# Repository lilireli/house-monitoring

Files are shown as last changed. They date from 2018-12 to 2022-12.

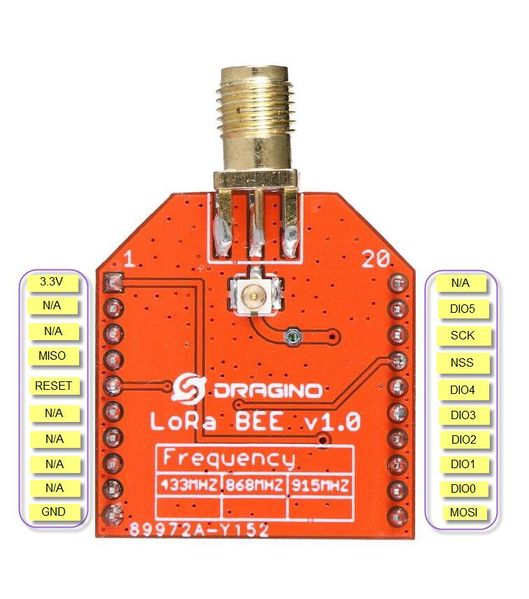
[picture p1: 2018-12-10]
sensor-transmitter/building-material/Dragino_LoRa_Bee.jpg

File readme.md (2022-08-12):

# House-Monitoring

This project contains the code and the schematics (3D printer code and electronic diagrams) for a deported temperature sensor.
It contains three parts:

- An Arduino sensor which contains a temperature sensor and a Lora transmitter,
- A Raspberry which contains a Lora receiver to get the data from the Arduino, and which sends it to a webserver,
- A Webserver which remembers past temperatures and displays it.

An example of usecase can be found in a family house where a wintergarden is at the back of the house, quite far away. 
However, it is necessary to monitor the temperature of this glass house. 
Thus, the Arduino is placed in the glass house, and the raspberry in the house, to control from afar the temperature. 
When not at home, the temperature can still be monitored with the web application.

## Sensor Transmitter
This is the Arduino part.

It contains:
- an arduino Nano
- a temperature sensor
- a Lora transmitter
- a LED (to check the device is working)

The code is done in C++, and compiled with Platformio.

## Receiver Transmitter
This is the Raspberry part.

It contains:
- a Raspberry
- a Lora receiver
- a buzzer (to alarm people when the temperature gets dangerous for the plants!)
- a LED screen (to print the current temperature and lowest temperature in the past 24 hours)

The code is done in C++.

Installation is done with cmake (version depends on the server your using)

```bash
mkdir build
cd build
sudo apt-get install libboost-all-dev
cmake ..
make
./house_transmitter --url http://localhost:5000/temp/add --auth-key 12345
```

## Server Monitoring
This is the webserver.

Initially it was done in C++, Vue.js (server-monitoring), in its new version it is in Python Django, React (server-monitoring2).

Installation with Python is done with virtualenv.

```bash
cd server-monitoring2
virtualenv venv
source venv/bin/activate
pip install requirements.txt
```

The application is currently running on Heroku
- To run locally https://devcenter.heroku.com/articles/getting-started-with-python#run-the-app-locally
- To deploy https://devcenter.heroku.com/articles/getting-started-with-python#deploy-the-app

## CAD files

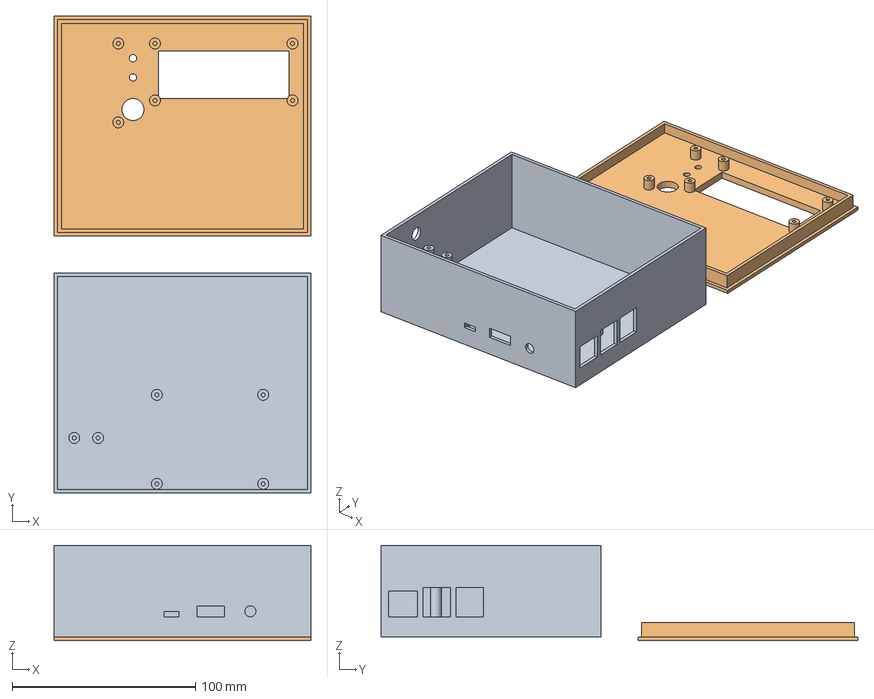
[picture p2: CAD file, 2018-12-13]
receiver-transmitter2/building-material/3d-printer/receptor.fcstd
140.0 x 260.0 x 52.0 mm
pocket lora antenna

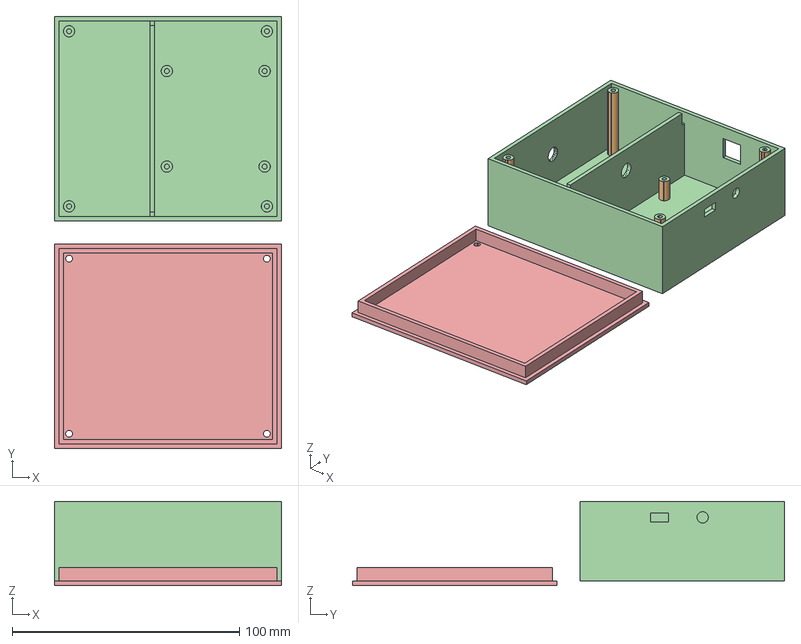
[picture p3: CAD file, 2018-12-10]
sensor-transmitter/building-material/3d-printer/sensor.fcstd
100.0 x 190.0 x 37.0 mm
footTop2
footTop2 (Meshed)
Pocket010 (Meshed)

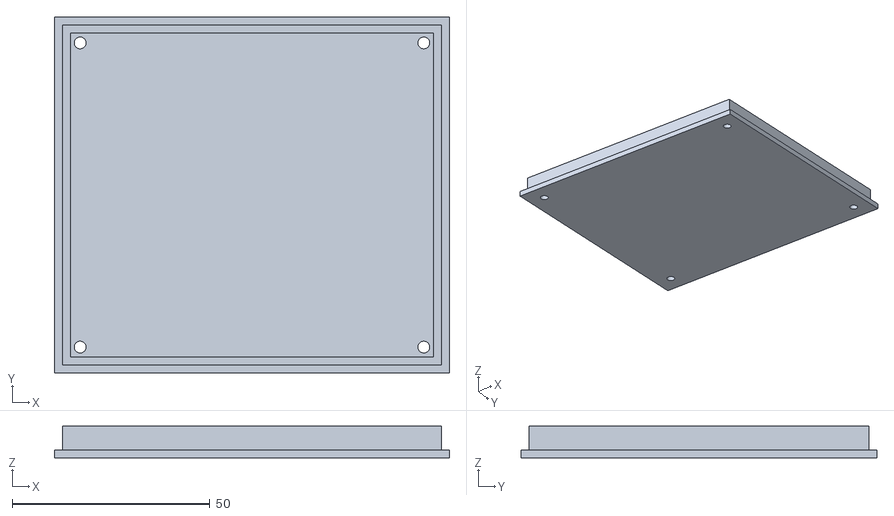
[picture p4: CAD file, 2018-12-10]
sensor-transmitter/building-material/3d-printer/arduino_top.stl
100.0 x 90.0 x 8.00

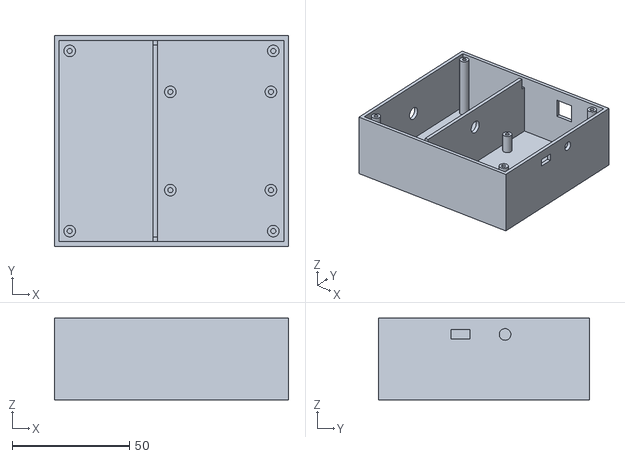
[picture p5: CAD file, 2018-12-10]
sensor-transmitter/building-material/3d-printer/arduino_bottom.stl
100.0 x 90.0 x 35.0

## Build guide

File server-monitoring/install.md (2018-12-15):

# Installation needs

## ZMQ
sudo apt-get install libzmq3-dev

## Sqlite
sudo apt-get install libsqlite3 libsqlite3-dev

## Boost
libboost-all-dev

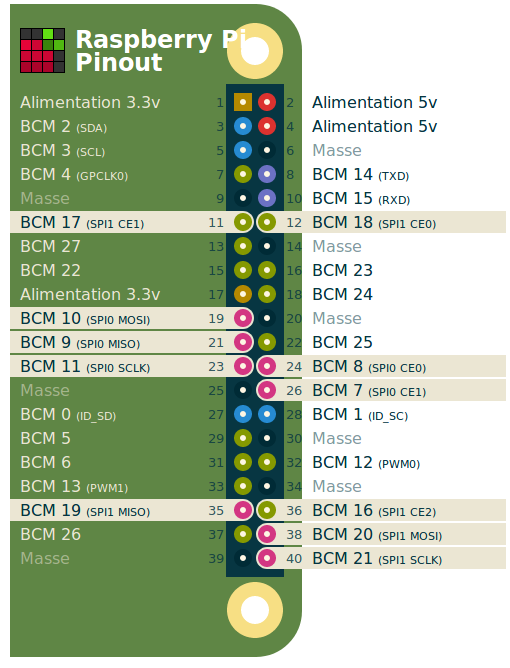
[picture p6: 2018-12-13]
receiver-transmitter2/building-material/Raspberry_pins.png

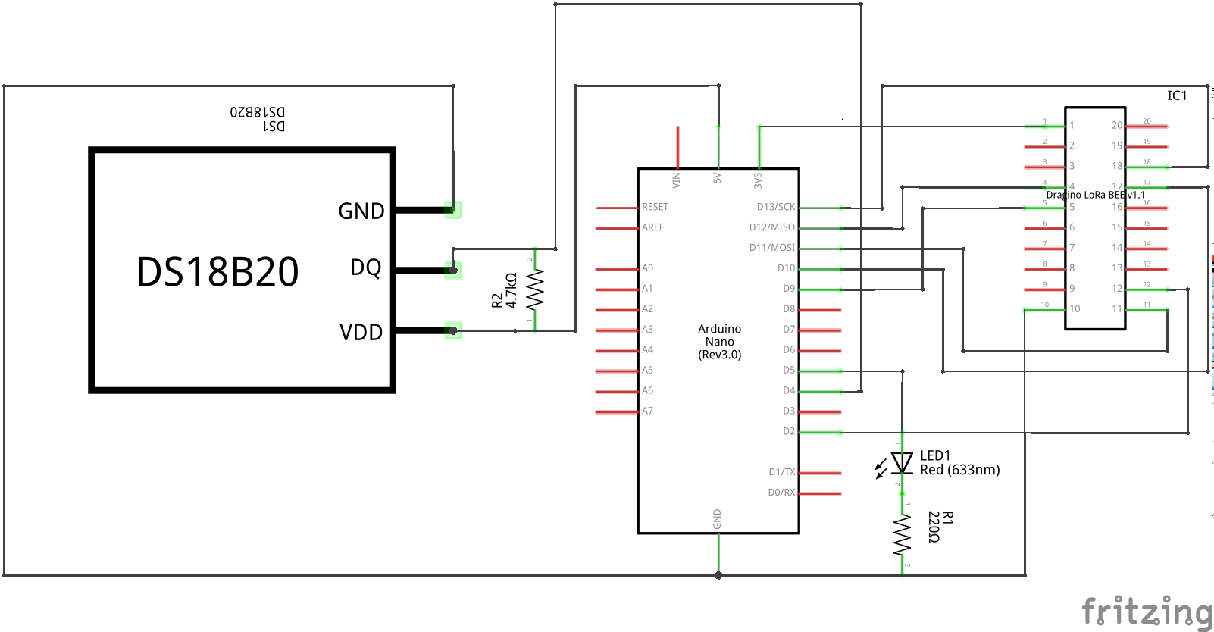
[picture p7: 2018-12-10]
sensor-transmitter/building-material/schema_arduino.png

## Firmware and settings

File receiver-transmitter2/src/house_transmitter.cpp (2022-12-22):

// Raspberry transmitter to retrieve the temperature through LoRa and resend it through Zmq

// Dragino Lora SPI Pins
///                 Raspberry    RFM95/96/97/98
///                 GND----------GND   (ground in)
///                 3V3----------3.3V  (3.3V in)
///  interrupt 0 pin 24----------DIO0  (interrupt request out)
///           SS pin 26----------NSS   (chip select in)
///          SCK pin 23----------SCK   (SPI clock in)
///         MOSI pin 19----------MOSI  (SPI Data in)
///         MISO pin 21----------MISO  (SPI Data out)

#include <house_transmitter.h>

namespace pt = boost::property_tree;
namespace po = boost::program_options;

//// Info Screen ////
InfoScreen::InfoScreen() : m_lcd(LCD_RS, LCD_E, LCD_D4, LCD_D5, LCD_D6, LCD_D7)
{
    m_lcd.begin(16, 2);
}

void InfoScreen::print_line_one(std::string text)
{
    m_lcd.setCursor(0, 0);
    m_lcd.print("                 ");
    m_lcd.setCursor(0, 0);
    m_lcd.print(text.c_str());
}

void InfoScreen::print_line_two(std::string text)
{
    m_lcd.setCursor(0, 1);
    m_lcd.print("                 ");
    m_lcd.setCursor(0, 1);
    m_lcd.print(text.c_str());
}

//// IHM ////
IHM::IHM() : m_alarm_enabled(false), m_running(true), m_alarm_running(false), m_noise_running(false), m_last_received(time(0))
{
    // Initialize actuators
    pinMode(LED_GREEN, OUTPUT);
    pinMode(LED_RED, OUTPUT);
    pinMode(ALARM, OUTPUT);

    digitalWrite(LED_GREEN, LOW);
    digitalWrite(LED_RED, LOW);
    digitalWrite(ALARM, LOW);

    m_info_screen.print_line_one("Hello");
    m_info_screen.print_line_two("v3");

    m_led_thread = std::make_unique<std::thread>(std::thread([this] {
        blink_led();
    }));
}

IHM::~IHM()
{
    std::cout << "Shutting down alarms" << std::endl;
    stop_alarm(99);
    m_running = false;
    m_led_thread->join();
    digitalWrite(LED_GREEN, LOW);
    digitalWrite(LED_RED, LOW);
    digitalWrite(ALARM, LOW);

    m_info_screen.print_line_one("Program not");
    m_info_screen.print_line_two("running");
}

void IHM::start_alarm(std::string error_msg)
{
    m_alarm_running = true;

    if (!m_noise_running && m_alarm_enabled && error_msg != "No webserver" && difftime(time(0), m_last_received) > WAITING_TIME_ALARM) {
        m_alarm_thread = std::make_unique<std::thread>(std::thread([this] {
            make_noise();
        }));
    }

    m_info_screen.print_line_two(error_msg);
}

void IHM::stop_alarm(float min_temp)
{
    m_alarm_running = false;
    m_last_received = time(0);

    if (m_noise_running) {
        m_alarm_thread->join();
    }

    std::stringstream temp_stream;
    temp_stream << std::fixed << std::setprecision(1) << min_temp;
    m_info_screen.print_line_two("min 24h:  " + temp_stream.str() + " C");
}

int IHM::print_temp(float temp)
{
    std::stringstream temp_stream;
    temp_stream << std::fixed << std::setprecision(1) << temp;
    m_info_screen.print_line_one("temp:     " + temp_stream.str() + " C");
}

void IHM::no_temp()
{
    m_info_screen.print_line_one("no temp");
}

void IHM::set_alarm_enabled(bool enable)
{
    std::cout << "Alarm set to " << enable << std::endl;
    m_alarm_enabled = enable;

    if (m_noise_running && !m_alarm_enabled) {
        m_alarm_thread->join();
    }
}

void IHM::make_noise()
{
    m_noise_running = true;

    while (m_alarm_running && m_alarm_enabled) {
        digitalWrite(ALARM, HIGH);
        std::this_thread::sleep_for(std::chrono::milliseconds(500));
        digitalWrite(ALARM, LOW);
        std::this_thread::sleep_for(std::chrono::milliseconds(500));
    }

    m_noise_running = false;
}

void IHM::blink_led()
{
    int current_led = LED_RED;

    while (m_running) {
        if (m_alarm_running) {
            current_led = LED_RED;
        } else {
            current_led = LED_GREEN;
        }

        digitalWrite(current_led, HIGH);
        std::this_thread::sleep_for(std::chrono::milliseconds(1000));
        digitalWrite(current_led, LOW);
        std::this_thread::sleep_for(std::chrono::milliseconds(1000));
    }
}

// LoRa Receiver ////
LoraReceiver::LoraReceiver() : m_rf95(RF_CS_PIN)
{
    // Initialize Pins
    if (!bcm2835_init()) {
        throw std::string("bcm2835_init() Failed\n\n");
    }

    std::cout << "RF95 CS=GPIO%d" << RF_CS_PIN
              << ", RST=GPIO%d" << RF_RST_PIN
              << std::endl;

    // Pulse a reset on module
    pinMode(RF_RST_PIN, OUTPUT);
    digitalWrite(RF_RST_PIN, LOW);
    bcm2835_delay(150);
    digitalWrite(RF_RST_PIN, HIGH);
    bcm2835_delay(100);

    if (!m_rf95.init()) {
        throw std::string("\nRF95 module init failed, Please verify wiring/module\n");
    }

    // check your country max power useable, in EU it's +14dB
    m_rf95.setTxPower(14, false);

    // Adjust Frequency
    m_rf95.setFrequency(RF_FREQUENCY);

    // If we need to send something
    m_rf95.setThisAddress(RF_NODE_ID);
    m_rf95.setHeaderFrom(RF_NODE_ID);

    // Be sure to grab all node packet
    // we're sniffing to display, it's a demo
    m_rf95.setPromiscuous(true);

    // We're ready to listen for incoming message
    m_rf95.setModeRx();

    std::cout << " OK NodeID=" << RF_NODE_ID << " @ "
              << std::fixed << std::setw(3) << std::setprecision(2)
              << RF_FREQUENCY << "MHz\n"
              << std::endl;
}

LoraReceiver::~LoraReceiver()
{
    std::cout << "Closing Lora connection" << std::endl;
    bcm2835_close();
}

int LoraReceiver::recv(float *temp)
{
    // We allow a timeout before sending error
    for (int i = 0; i < 60; i++) {
        if (m_rf95.available()) {
            // Should be a message for us now
            uint8_t buf[RH_RF95_MAX_MESSAGE_LEN];
            uint8_t len = sizeof(buf);

            if (m_rf95.recv(buf, &len)) {
                try {
                    std::cout << "Data: " << (char *)buf << std::endl;

                    // We need to remove unuseful characters at the end of the string
                    std::string req_corrupt = std::string((char *)buf);
                    std::size_t req_corrupt_end = req_corrupt.find("}");

                    if (req_corrupt_end == std::string::npos) {
                        std::cout << "Received badly formatted message";
                        throw std::string("Badly formatted\n");
                    }

                    std::istringstream req(req_corrupt.substr(0, req_corrupt_end + 1));
                    pt::ptree root;

                    pt::read_json(req, root);
                    // Not used yet -> std::string device = root.get<std::string>("id");
                    *temp = root.get<float>("temp");

                    return 1;
                } catch (...) {
                    std::cout << "No temperature received from sensor" << std::endl;
                }
            }
        }

        // wait one more sec to have result
        bcm2835_delay(1000);
    }

    // Alert no data received after one minute
    std::cout << "No temperature received from sensor" << std::endl;
    return -1;
}

//// HTTP Sender ////
int HttpSender::add_new_value(float temp, std::string status, bool *alarm_enabled)
{
    time_t now = time(0);
    int hasFailed = 0;

    if (m_curr_bucket == 0) {
        m_curr_bucket = now;
    }

    if (difftime(now, m_curr_bucket) > DB_INSERT_INTERVAL) {
        std::cout << "Sending data\n";
        float average = std::accumulate(m_temps.begin(), m_temps.end(), 0.0) / m_temps.size();

        hasFailed = send_temperature(m_curr_bucket, average, status, alarm_enabled);

        m_curr_bucket = now;
        m_temps.clear();
    }

    m_temps.push_back(temp);

    return hasFailed;
}

int HttpSender::send_temperature(time_t datetime, float temp, std::string status, bool *alarm_enabled)
{
    try {
        // check datetime
        struct tm *timeinfo = localtime(&datetime);
        char datetime_str[30];
        strftime(datetime_str, 30, "%Y-%m-%dT%H:%M:%S", timeinfo);

        // create message
        std::ostringstream body_stream;

        body_stream << std::setprecision(2) << std::fixed
                    << "datetime=" << datetime_str << "&"
                    << "temperature=" << temp << "&"
                    << "alarm_current=" << status << "&"
                    << "auth_key=" << m_auth_key;

        std::string body = body_stream.str();

        // send it
        http::Request request{m_url};

        const auto response = request.send("POST", body, {{"Content-Type", "application/x-www-form-urlencoded"}});

        std::string result = std::string{response.body.begin(), response.body.end()};

        std::cout << "Received from webserver: " << result << '\n';

        if (result == "{\"alarm\": \"on\"}") {
            std::cout << "Alarm enabled\n";
            *alarm_enabled = true;
        } else {
            std::cout << "Alarm disabled\n";
            *alarm_enabled = false;
        }

    } catch (const std::exception &e) {
        std::cerr << "Request failed, error: " << e.what() << '\n';
        return 1;
    }

    return 0;
}

TempKeeper::TempKeeper()
{
    for (int i = 0; i < SIZE_TEMP_KEEPER; i++) {
        m_temp_24h.push_back(99);
    }
}

void TempKeeper::add(float temp)
{
    time_t now = time(0);
    struct tm *timeinfo = localtime(&now);
    int approx_curr_pos = 60 * timeinfo->tm_hour + timeinfo->tm_min;
    int curr_pos = approx_curr_pos / PRECISION_KEEPER;

    // Erase old values
    int erase_pos = (curr_pos < SIZE_TEMP_KEEPER - 1) ? curr_pos + 1 : 0;
    m_temp_24h[erase_pos] = 99;

    // Compare new one with running 15 min
    if (m_temp_24h[curr_pos] > temp) {
        m_temp_24h[curr_pos] = temp;
    }
}

float TempKeeper::min_24h()
{
    auto min = std::min_element(m_temp_24h.begin(), m_temp_24h.end());
    return *min;
}

//Flag for Ctrl-C
volatile sig_atomic_t force_exit = false;

void sig_handler(int sig)
{
    std::cout << "\nBreak received, exiting!" << std::endl;
    force_exit = true;
}

// Main Function
int main(int argc, const char *argv[])
{
    // * Parsing arguments *
    std::string url, auth_key;

    po::options_description desc("Transmitter for house-monitoring project");
    desc.add_options()("help,h", "produce help message")("url", po::value<std::string>(), "defines to which url send the data")("auth-key", po::value<std::string>(), "defines the key to authenticate to the server");

    po::variables_map vm;
    po::store(po::parse_command_line(argc, argv, desc), vm);
    po::notify(vm);

    if (vm.count("help")) {
        std::cout << desc << std::endl;
        return 1;
    }

    // Deactivate server as long as no option found
    // if (vm.count("url")) {
    //     url = vm["url"].as<std::string>();
    // } else {
    //     std::cout << "No url was provided." << std::endl;
    //     return 1;
    // }

    // if (vm.count("auth-key")) {
    //     auth_key = vm["auth-key"].as<std::string>();
    // } else {
    //     std::cout << "No auth-key was provided." << std::endl;
    //     return 1;
    // }

    // * Main program *
    std::cout << "Starting program" << std::endl;

    // Register handler
    signal(SIGINT, sig_handler);

    LoraReceiver lora_receiver;
    // HttpSender http_sender(url, auth_key);
    IHM ihm;
    TempKeeper temp_keeper;

    std::map<std::string, std::string> errors = {
        {"tempLow", "Temp too low"},
        {"errArduino", "No temp received"},
        {"errWebserver", "No webserver"}};

    while (!force_exit) {
        float temp = 99;
        bool alarm_enabled = ihm.get_alarm_enabled();
        std::string status = "ok";
        std::string print_status = "";

        if (lora_receiver.recv(&temp) > 0) {
            temp_keeper.add(temp);
            ihm.print_temp(temp);
            if (temp < TRIGGER_TEMP) {
                status = "tempLow";
            }
        } else {
            ihm.no_temp();
            status = "errArduino";
        }

        // if (http_sender.add_new_value(temp, status, &alarm_enabled) > 0) {
        //     if (status == "ok") {
        //         status = "errWebserver";
        //     }
        // }

        // if (ihm.get_alarm_enabled() != alarm_enabled) {
        //     ihm.set_alarm_enabled(alarm_enabled);
        // }

        // if (status == "ok") {
        //     ihm.stop_alarm(temp_keeper.min_24h());
        // } else {
        //     ihm.start_alarm(errors[status]);
        // }
    }

    return 0;
}

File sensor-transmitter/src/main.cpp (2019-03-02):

// Arduino sensor to retrieve the temperature and send it through LoRa

// Dragino Lora SPI Pins
///                 Arduino      RFM95/96/97/98
///                 GND----------GND   (ground in)
///                 3V3----------3.3V  (3.3V in)
/// interrupt 0 pin D2-----------DIO0  (interrupt request out)
///          SS pin D10----------NSS   (chip select in)
///         SCK pin D13----------SCK   (SPI clock in)
///        MOSI pin D11----------MOSI  (SPI Data in)
///        MISO pin D12----------MISO  (SPI Data out)

#include <Arduino.h>

//Include required lib so Arduino can talk with the Lora Shield
#include <SPI.h>
#include <RH_RF95.h>

/* Dependancy for the bus 1-Wire */
// In here we have a DS18B20 temperature sensor
#include <OneWire.h>

// Singleton instance of the radio driver
RH_RF95 rf95;
int temp_pin = 4;
int led_pin = 5;
float temperature;
String datastring="";
char databuf[10];
uint8_t dataoutgoing[40];

/* Return codes for the function getTemperature() */
enum DS18B20_RCODES {
    READ_OK,  // Reading ok
    NO_SENSOR_FOUND,  // No Sensor
    INVALID_ADDRESS,  // Received address unvalid
    INVALID_SENSOR  // Sensor unvalid (not a DS18B20)
};

/* OneWire object */
OneWire ds(temp_pin);

byte getTemperature(float *temperature, byte reset_search);

void setup()
{
    Serial.begin(9600);
    if (!rf95.init())
    Serial.println("init failed");
    // Defaults after init are 868.0Mhz, 13dBm, Bw = 125 kHz, Cr = 4/5,
    //                         Sf = 128chips/symbol, CRC on
    // Can be changed in RH_RF95.cpp

    pinMode(led_pin, OUTPUT);
}

void loop()
{
    /* Read ambient temperature at ~1Hz */
    if (getTemperature(&temperature, true) != READ_OK) {
        Serial.println(F("Erreur de lecture du capteur"));
        return;
    }

    /* Print temperature (for debug purpose) */
    // Serial.print("Temperature : ");
    // Serial.print(temperature, 2);
    // Serial.print("C");
    // Serial.println();
    //
    // Serial.println("Sending to rf95_server");

    digitalWrite(led_pin, HIGH);
    datastring = "";
    datastring += "{\"id\": \"serre001\", \"temp\": ";
    datastring += dtostrf(temperature, 4, 2, databuf);
    datastring += "}";
    strcpy((char *)dataoutgoing,datastring.c_str());

    rf95.send(dataoutgoing, sizeof(dataoutgoing));
    rf95.waitPacketSent();

    delay(1000);
    digitalWrite(led_pin, LOW);
    delay(3000);
}

/**
* Reading from a sensor DS18B20.
*/
byte getTemperature(float *temperature, byte reset_search) {
    byte data[9], addr[8];
    // data[] : Data read from the scratchpad
    // addr[] : Detected address for the bus onewire

    /* Reset the bus 1-Wire if necessary (needed to read the first sensor) */
    if (reset_search)
        ds.reset_search();

    if (!ds.search(addr))
        return NO_SENSOR_FOUND;

    if (OneWire::crc8(addr, 7) != addr[7])
        return INVALID_ADDRESS; // CRC is not valid

    if (addr[0] != 0x28) // address 0x28 for DS18B20 and 0x10 for DS18S20
        return INVALID_SENSOR; // Device family not recognized

    /* Reset the bus 1-Wire and select the sensor */
    ds.reset();
    ds.select(addr);

    /* Start a measurement and wait for the end of it */
    ds.write(0x44, 1); // start conversion, with parasite power on at the end
    delay(800);

    /* Reset the bus 1-Wire, select the sensor and send a request to the scratchpad */
    ds.reset();
    ds.select(addr);
    ds.write(0xBE);  // Read Scratchpad

    /* Read the scratchpad */
    for (byte i = 0; i < 9; i++)
        data[i] = ds.read();

    /* Calculate the temperature in degree celsius */
    *temperature = (int16_t) ((data[1] << 8) | data[0]) * 0.0625;

    return READ_OK;
}

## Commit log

2018-12-10 feat: added schematics and updated webserver
    [arduino_bottom.stl, arduino_top.stl, schema.fzz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]
2018-12-13 feat: updated transmitter with zeromq inside
    [receptor.fcstd]
2018-12-15 feat: adding threads
2018-12-15 feat: reorganised folder, cleaned arduino and updated webserver
    [arduinoBox.stl, arduino_bottom.stl, arduino_top.stl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]
2018-12-16 feat: added correct handling of errors
    [house_transmitter.cpp, house_transmitter.h]
2018-12-16 bugfix: corrected error in arduino
    [house_transmitter.cpp]
2018-12-19 feat: better error handling zmq
    [house_transmitter.cpp, house_transmitter.h]
2018-12-23 updated order of error msg
    [house_transmitter.cpp]
2018-12-25 feat: changed limit temperature
2018-12-28 feat: changed place to check if temperature is right
2019-02-26 updated msg sensor, receiver timeout and added blinking
2019-03-02 bug: solve arduino msg and raspberry init
    [house_transmitter.cpp, main.cpp]
2019-12-24 added last 24h temp on raspberry
2019-12-25 corrected backward modification error
    [house_transmitter.cpp]
2022-08-11 debug thread zmq
2022-08-11 removed zmq wip
    [receptor.fcstd]
2022-08-12 communication raspberry server
2022-12-22 feat(raspberry): remove server
2022-12-22 feat(raspberry): add version
2022-12-22 feat(raspberry): update messages raspberry
